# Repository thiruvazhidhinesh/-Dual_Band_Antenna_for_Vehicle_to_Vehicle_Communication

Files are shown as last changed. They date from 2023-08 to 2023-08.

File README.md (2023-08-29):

# Dual_Band_Antenna_for_Vehicle_to_Vehicle_Communication

<br>
In this project, a dual-band shared aperture antenna array is designed that operates 
at both the current Dedicated Short Range Communications (DSRC) band (viz. 5.9 GHz) 
and the future 5G millimeter-wave (mm-wave) band allocated for vehicle-to-vehicle 
(V2V) communications. The design consists of a 2 x 2 differentially fed patch array 
operating at 5.9 GHz, co-printed with a 1 x 2 series fed array operating on a single-layer 
substrate. Two antenna arrays have been designed using two different substrates: Rogers 
RT Duroid 5880 and FR4, and the effect of substrate material type on antenna 
performance has been studied. In particular, the shared aperture array designed using
Rogers operates from 5.854–6.001 GHz (DSRC band) with a bandwidth of 147 MHz and 
a gain of 10.63 dB intended for V2V communication. It also operates from 25.626-26.362 
GHz (5G mm-wave band) with a bandwidth of 736 MHz and a gain of 9.778 dB intended 
for 5G mm-wave communication. The ports of the array are highly isolated, with an 
isolation of greater than 50 dB between the DSRC band port and the 5G mm-wave band 
port

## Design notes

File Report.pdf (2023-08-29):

i

## LOW PROFILE DUAL BAND SHARED ANTENNA ARRAY FOR VECHICLE TO VECHICLE COMMUNICATION

Submitted by

THIRUVAZHI DHINESH KUMAR S (2019105594)

GOWTHAM N (2019105532)

DINESH M (2019105526)

KAVIYARASAN K (2019105021)

In partial fulfillment for the award of the degree of

BACHELOR OF ENGINEERING

in

ELECTRONICS AND COMMUNICATION ENGINEERING

COLLEGE OF ENGINEERING, GUINDY

ANNA UNIVERSITY::CHENNAI 600025

MAY 2023

i

APPENDIX 2

### ANNA UNIVERSITY: CHENNAI 600 025

BONAFIDE CERTIFICATE

Certified that this project report LOW PROFILE DUAL BAND SHARED ANTENNA

ARRAY FOR VECHICLE TO VECHICLE COMMUNICATION is the bonafide,

work of GOWTHAM N who carried the project work under my supervision.

SIGNATURE | SIGNATURE

Dr.M.Meenakshi

HEAD OF THE DEPARTMENT

PROFESSOR

DEPARTMENT OF ECE

COLLEGE OF ENGINEERING, GUINDY

ANNA UNIVERSITY

CHENNAI-600 025

Dr.M.Shanmugapriya

SUPERVISOR

ASSISTANT PROFESSOR

DEPARTMENT OF ECE

COLLEGE OF ENGINEERING, GUINDY

ANNA UNIVERSITY

CHENNAI-600 025

ii

ACKNOWLEDGEMENT

First and foremost, we thank God for an abundance of grace and has countless blessings

in making this work a great success.

We also express our sincere gratitude to our Head of the Department

Dr.M.MEENAKSHI, Professor, Department of Electronics and Communication

Engineering for her enthusiastic encouragement and support throughout the project.

We present our sincere thanks and gratitude to our project supervisor,

Dr.M.SHANMUGAPRIYA, Assistant Professor, Department of Electronics and

Communication Engineering for his wholehearted support, patience, valuable guidance,

technical expertise and encouragement in our project.

We thank all the teaching and non-teaching staff of Department of Electronics and

Communication Engineering, for their kind help and co-operation during the course of our

project.

iii

Chapter | Section | Title | Page
No. | No. | | No.
| | Abstract | i
| | List of Tables | iii
| | List of Figures | iv
1 | | Introduction | 1
| 1.1 | Motivation | 2
| 1.2 | Software Requirement | 3
| 1.3 | Software Overview | 3
2 | | Literature Survey | 4
3 | | Simulation Design Methodology and Results
3.1 | Design flow | 6
3.2 | CST Procedure | 9
3.3 | Analysis I | 10
3.4 | Analysis II | 15
3.5 | Analysis III | 21
3.6 | Analysis IV | 28
4 | Fabrication Process
4.1 | Laser cum chemical etching | 24
4.2 | Final Preparations | 27
4.3 | Laser depaneling | 28
4.4 | Network Analyzer | 29
4.5 | Calibration kit | 30
4.6 | SMA connector | 31
5 | Fabrication results
5.1 | Results | 33
6 | Conclusion | 36
| References | 37

APPENDIX 3

TABLE OF CONTENTS

i

ABSTRACT

In this project, a dual-band shared aperture antenna array is designed that operates

at both the current Dedicated Short Range Communications (DSRC) band (viz. 5.9 GHz)

and the future 5G millimeter-wave (mm-wave) band allocated for vehicle-to-vehicle

(V2V) communications. The design consists of a 2 x 2 differentially fed patch array

operating at 5.9 GHz, co-printed with a 1 x 2 series fed array operating on a single-layer

substrate. Two antenna arrays have been designed using two different substrates: Rogers

RT Duroid 5880 and FR4, and the effect of substrate material type on antenna

performance has been studied. In particular, the shared aperture array designed using

Rogers operates from 5.854–6.001 GHz (DSRC band) with a bandwidth of 147 MHz and

a gain of 10.63 dB intended for V2V communication. It also operates from 25.626-26.362

GHz (5G mm-wave band) with a bandwidth of 736 MHz and a gain of 9.778 dB intended

for 5G mm-wave communication. The ports of the array are highly isolated, with an

isolation of greater than 50 dB between the DSRC band port and the 5G mm-wave band

port.

ii

iii

LIST OF FIGURES

Figure No. | Title | Page No.
1 | Antenna design | 6
2 | Antenna array for DSRC band (CST Simulation) | 7
3 | Antenna array for 5G mm wave band (CST Simulation) | 8
4 | Design of combined arrays | 9
5 | Modified design with truncated corners and cross slots in 5.9 GHz array | 10
6 | Modified design with truncated corners and cross slots in 5.9 GHz array and cross slots in 5G mm wave band array | 10
7 | Modified design with cross slots in 5.9 GHz array and 5G mm wave band array | 11
8 | FR4 design | 11
9 | Modified FR4 design with truncated corners | 12
10 | S11 plot of design containing only 5.9 GHz array | 14
11 | S22 plot of design containing only 28 GHz array | 15
12 | VSWR plot of design containing only 5.9 GHz array | 15
13 | VSWR plot of design containing only 28 GHz array | 15
14 | S11 plot of 5.9 GHz array | 17
15 | S22 plot of 28 GHz array | 17
16 | VSWR plot for 5.9 GHz array | 18
17 | VSWR plot for 28 GHz array | 18
18 | Port 1 (5.9 GHz array) is excited | 19
19 | Port 2 (28 GHz array) is excited | 19
20 | Design without 180º Phase shift | 19

iv

Figure No. | Title | Page No.
21 | Design with 180º Phase shift | 19
22 | Varying patch length (Lp) of the DSRC band array | 22
23 | Varying patch width (Wp) of the DSRC band array | 22
24 | Varying patch length (LUp) of the 5G band array | 23
25 | Varying patch width (WUp) of the 5G band array | 23
26 | Varying thickness of the substrate EPOCH 1 | 24
27 | Varying thickness of the substrate EPOCH 2 | 24
28 | Varying thickness of the substrate EPOCH 3 | 24
29 | S11 Plot after slot introduction | 25
30 | S22 Plot after slot introduction | 25
31 | . Radiation pattern of shared array at 5.9 GHz – Rogers based design | 26
32 | Radiation pattern of shared array at 26 GHz – Rogers based design | 26
33 | VSWR at 5.9 GHz – Rogers based design | 27
34 | VSWR at 26 GHz – Rogers based design | 27
35 | Axial ratio at DSRC band– Rogers based design | 28
36 | Axial ratio at 5G mm-wave band– Rogers based design | 28
37 | S11 Plot for 5.9 GHz array – FR4 based design | 29
38 | S22 Plot for 5G mm-wave band – FR4 based design | 29
39 | Radiation pattern of shared array at 5.9 GHz – FR4 based design | 30
40 | Radiation pattern of shared array at 5G mm-wave band – FR4 based design | 30
41 | VSWR at 5.9 GHz – FR4 based design | 31

v

Figure No. | Title | Page No.
42 | VSWR at 5G Band – FR4 based design | 31
43 | Axial ratio at 5.9 GHz – FR4 based design | 31
44 | Axial ratio at 5G band – FR4 based design | 32
45 | RAYCUS LASER | 34
46 | IPG LASER | 34
47 | After reaction with FeCl3 | 35
48 | During tinning process | 36
49 | During Grinding process | 36
50 | LPKF Machine | 37
51 | Gerber of the array | 38
52 | Insertion of drills beats | 38
53 | Etched Substrate | 39
54 | Soldered ports | 39
55 | Vector Network Analyzer | 40
56 | Calkit 85220A | 40
57 | SMA Connector | 41
58 | Measured S11 of DSRC band | 42
59 | Measured VSWR at DSRC band | 43

vi

LIST OF TABLES

Table No. | Title | Page No.
1 | Dimensions for 5.9 GHz array | 7
2 | Dimensions for 5G mm-wave band antenna array | 8
3 | Dimensions for Antenna design using FR4 substrate | 12
4 | Dimensions for Antenna design using FR4 substrate with truncated corners | 13
5 | Radiation plots of individual antenna arrays | 16
6 | Radiation plots for combined array antenna design | 18
7 | Results without 180º Phase shift – 5.9 GHz array | 20
8 | Results with 180º Phase shift – 5.9 GHz array | 20
9 | Results without 180º Phase shift – 28 GHz array | 20
10 | Results with 180º Phase shift – 28 GHz array | 20
11 | Simulation results for 5.9 GHz array - Rogers based design | 26
12 | Simulation results for 26 GHz array - Rogers based design | 26
13 | Simulation results for 5.9 GHz array – FR4 based design | 30
14 | Simulation results for 5G mm-wave band – FR4 based design | 30

### CHAPTER 1

### INTRODUCTION

### 1.1 MOTIVATION:

Globally, road accidents claim 1.3 billion lives per year. Particularly in the US, road

accidents result in 38 thousand deaths per year. Improving the safety of the drivers is one of

the primary goals of the intelligent transportation system. The Federal Communications

Commission (FCC) allocated the 5.85-5.925GHz Dedicated Short Range Communications

(DSRC) band in the intelligent transport system (ITS) radio for vehicular communications.

This enabled the development of a virtual traffic light (VTL) algorithm to reduce traffic

congestion using vehicle-to-vehicle communication (V2V) and internet of things (IoT)

technologies. The role of the algorithm is to collect data such as speed, acceleration, and

direction of the vehicle from nearby vehicles as well as to control traffic without using

physical traffic lights. Field trials conducted in Pittsburgh showed that VTL can effectively

reduce 1) road accidents at the intersections by 70%, 2) carbon emissions, and 3) commute

time from 30.7 to 18.3 minutes. Currently, the US Department of Transportation and various

automobile industries use the 5.9 GHz safety band for automatic toll collection, traffic

congestion control, emergency vehicle warning, and intersection movement warning.

However, due to bandwidth restriction in the DSRC band, high data rate communications,

such as video streaming, are quite difficult to achieve. Therefore, the trend is to move

towards the millimeter-wave (mm-wave) spectrum for higher speed communications of >1

Gbps with wider bandwidth and reduced interference. In addition, the radios at mm-wave

are smaller in size and require low power consumption, implying inconspicuous integration

on the vehicular platforms. However, mm-wave spectrum suffers from large propagation

and atmospheric losses as well as attenuation due to rain and severe weather conditions.

These losses can be compensated by using high gain antenna arrays. Importantly, we need

a system capable of switching between the 5G mm-wave band, for high speed

communications, and well-established the DSRC band to meet the required communication

link quality of service during severe weather conditions.

Radios that can operate in the traditional low frequency bands and the new mm-wave

bands are called non-standalone devices. The main challenge is implementing these devices

in a single compact package when the two frequency bands are widely separate with a band

ratio >2:1. These dual-band systems offer high jamming, and interference protection, as well

as improvement in the channel capacity by making use of frequency diversity. Traditionally,

dual-band radios employ antennas designed using two separate single-band antennas or a

single structure that resonates at both bands. Various works have been reported of multi-

band antennas using a single feed. However, these single feed dual-band antennas require

additional RF components in the front-end for separate multiband operation. A more

efficient design for multiband operation is to use separate feed network for each operating

frequency bands by adopting a single or multilayer design. The main drawback of multilayer

designs are the multilayer fabrication technique that is expensive and increases the size of

the array. One of the simple, and easy fabrication technique is using a single layer Printed

Circuit Board (PCB). The implemented PCB shared aperture array operates at dual band

with highly isolated ports and provides gain improvement at upper band by utilizing the

higher order modes of the lower band array. In this work, a low profile non-standalone,

dual-band, shared aperture antenna array with gain improvement is designed for V2V

communication. The designed array consists of 4 patch antennas operating at 5.9 GHz

(DSRC) with a differential coax feed network and 2 patch antennas operating at 28 GHz

(5G mm-wave) with a series coax feed network, as shown. The array provides a dual-band

operation with high gain, high port-to-port isolation, and high efficiency.

### 1.2 SOFTWARE REQUIREMENT:

CST STUDIO SUITE

### 1.3 SOFTWARE OVERVIEW:

The designs and simulations in this project are based on the Computer Simulation

Technology (CST) microwave Studio suite which is a high performance electromagnetic

simulation software. There are two basic solver modules provided: time domain solver and

frequency domain solver. The two solvers are totally different. Time domain solver is used

for non-resonant structures and frequency domain solver contains alternatives for highly resonant structures. Beside frequency domain solver has the option of utilizing tetrahedral

mesh that can discrete the structure better which is not available with in time domain solver.

In addition, time domain solver is only for normal incidence but frequency domain solver

can be used for off–normal incidences. CST contains several different simulation methods,

including the finite integration technique(FIT), finite element method (FEM), transmission

line matrix (TLM), multilevel fast multiples method (MLFMM) and particle in cell (PIC),as

well as Multiphysics solvers for other domains of physics with links to electromagnetics.

### CHAPTER 2

### LITERATURE SURVEY

### 2.1.1 Low Profile Dual-Band Shared Aperture Array for Vehicle-to-

Vehicle Communication

In this paper, it was observed that a non-standalone dual-band shared aperture

antenna array can be operated at both the current Dedicated Short-Range Communications

(DSRC) band (viz. 5.9 GHz) and the future 5G millimeter-wave (mm-wave) band (viz. 28

GHz) allocated for vehicle-to-vehicle (V2V) communications.

### 2.1.2 Left-Handed Circularly Polarized Two-Element Antenna Array for

Vehicular Communication

From this paper, it was observed that truncated opposite corners and introduction

of cross slots move the polarization of an antenna from linear towards circular and cause

narrow beam width.

2.1.3 Vehicle Platform Effects on Performance of Flexible, Lightweight,

and Dual-Band Antenna for Vehicular Communications

From this paper, the impact of the ground, of the vehicle surroundings and of the

car body on signal transmission and reception of a dual-band microwave antenna tested

on two automotive plastic parts on a convertible vehicle for cellular and Cellular - Vehicle

to Everything (C-V2X) communications was observed.

### 2.1.4 Combined LTE and IEEE 802.11p Antenna for Vehicular

Applications From this paper, the evolution of IEEE 802.11 to IEEE 802.11p with

added V2V and V2X technologies which focuses on traffic safety and traffic efficiency

has been observed. The observed results show that the antennas are well matched and well

isolated for both LTE and V2X.

### 2.1.5 A Hybrid-Equivalent Surface-Edge Current Model for Simulation

of V2X Communication Antennas with Arbitrarily Shaped Contour

From this paper, it was observed that equivalent models of antennas are useful for

the fast simulation of vehicle-to-everything (V2X) communication. However, the full-

wave methods are accurate but computationally intensive, and they need a

supercomputing platform to simulate V2X communication.

### 2.1.6 A Pillbox Based Dual Circularly-Polarized Millimeter-Wave Multi-

Beam Antenna for Future Vehicular Radar Applications

From this paper, it was observed that a series-fed microstrip line based dual CP

leaky-wave antenna (LWA) array, which has a symmetrical structure can be used to obtain

both left-hand circular polarization (LHCP) and right-hand circular polarization (RHCP)

by switching the exciting current direction of the microstrip line.

### 2.1.7 A dual band omni-directional antenna for WAVE and Wi-Fi

From this paper, it was observed that a dual band antenna is capable of operating in

both the WAVE and Wi-Fi bands. This antenna is observed to be simple, easy-to-produce

and inexpensive; it can be a cost-effective alternative to use of multiple directional

antennas for vehicles.

2.1.8 A Miniaturized Wideband Antenna for Vehicular Communication,

WiMAX, and WLAN Applications

From this paper, it was observed that Rogers RT/Duroid 5880 TM with dielectric

constant 2.2 and loss tangent tan δ = 0.0009 has lower loss, higher efficiency and wider

bandwidths can be achieved. And also, with an increase in permittivity, the capacitance

increases. With an increase in capacitance, the resonant frequency decreases.

### CHAPTER 3

### SIMULATION DESIGN METHODOLOGY AND RESULTS

### 3.1 DESIGN FLOW:

### 3.1.1 Design flow using Rogers substrate:

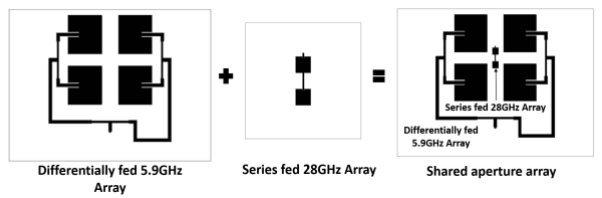
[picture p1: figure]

Figure 1. Antenna design

The proposed antenna structure as per the base reference paper consists of two main parts,

as shown in Figure. 1, the first part 5.9GHz differential fed array and the second part is

series fed 5G mm wave array. Each of the array and coaxially fed and printed upon Rogers

substrate. A 28GHz array has been inserted in a space between the 5.9GHz array for future

5G mm wave communication.

Figure 2. Antenna array for DSRC band (CST Simulation)

Table 1: Dimensions for 5.9 GHz array

Initially, the antenna array design for 5.9 GHz has been completed as in Figure 2 with

differential feeding and simulated to observe the results without presence of a second port

in order to compare the results obtained with presence of another port for 5G mm wave

band which provides information about the isolation between the ports. Then, another new

antenna array for 5G mm wave band has been completed as in Figure 3 with serial feeding

and similarly simulation has been done to observe the results without presence of first port

which was used for 5.9 GHz.

PARAMETERS | VALUES(mm)
W x L x h | 75 x 100 x 0.52
Wp x Lp x hp | 19 x 16.7 x 0.035
x | 8
y | 6
Wf x Lfi x hf | 1.6 x 5.85 x 0.035
W50Ω | 1.6
W70.7Ω | 0.9
Wgap | 0.16

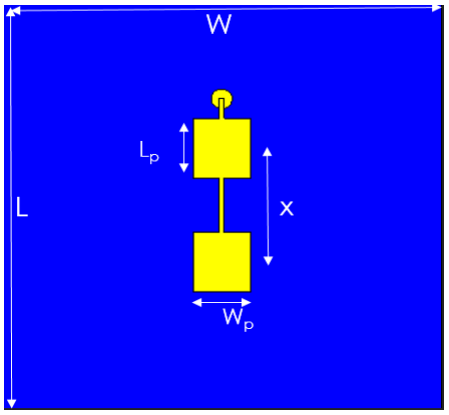
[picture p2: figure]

Figure 3. Antenna array for 5G mm wave band (CST Simulation)

Table 2: Dimensions for 5G mm wave band antenna array

After obtaining the results of separate antenna arrays from simulation, both these arrays

are mounted on a Rogers substrate material to obtain the results with presence of both

ports – Port 1 and Port 2 which are used for exciting 5.9 GHz and 5G mm wave frequency

band. In the combined design, 5.9 GHz array is fed using differential feeding and 5G mm

wave band array is fed using serial feeding so that the latter can be placed in the space

available within the former and the dimensions of both these arrays are same as of the

individual array antennas. The antenna array design for combined applications of DSRC

band and 5G mm wave band has been completed as in Figure 4 and the results obtained

is discussed in section 3.3 .

PARAMETERS | VALUES(mm)
W x L x h | 25 x 25 x 0.52
Wp x Lp x hp | 3.25 x 3.67 x 0.035
x | 8
Wf x Lfi x hf | 0.3 x 1.24 x 0.035

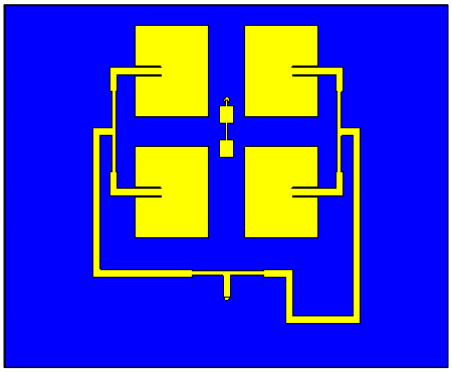
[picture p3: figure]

Figure 4. Design of combined arrays

Using the design shown in Figure 4, the resonant frequencies obtained were 5.97

GHz and 28 GHz. For V2V communication the resonant frequency should be 5.9 GHz.

In India for 5G, 26 GHz is in use. So to shift the frequencies to left, slots were introduced

and the corners of each patch are truncated as shown in Figure 5. Introduction of cross

slots, brings forth the advantage of replacing a single radiating element with three

radiating elements in place. Increasing the radiating elements with small distance of

separation between the elements will narrow down the radiation and increase directivity

along with gain. Introducing truncated corners in the regions of the patch where surface

current is minimum enhances the performance of the antenna and moves the polarization

type of the antenna from linear to circular polarization. Considering these advantages,

modifications in the design has been performed through series of parameter sweeps and

analysis of surface current distribution. With the design shown in Figure 4, three different

modified arrays have been designed as shown in the following figures.

Figure 5. Modified design with truncated corners and cross slots in 5.9 GHz array

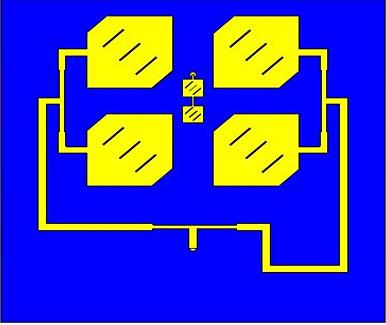
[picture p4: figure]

Figure 6. Modified design with truncated corners and cross slots in 5.9 GHz array and

cross slots in 5G mm wave band array

Figure 7. Modified design with cross slots in 5.9 GHz array and 5G mm wave band

array

### 3.1.1 Design flow using FR4 substrate:

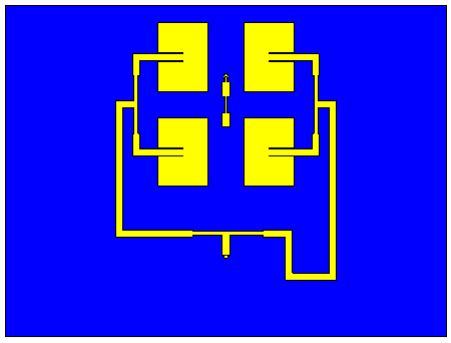
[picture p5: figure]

Figure 8. FR4 design

Previous designs were made on substrate based on Rogers. Rogers can be

used in any environment. But in V2V communication FR4 can also be used, since the

environment does not cause a major impact on the performance of the antenna. Using

FR4, the antenna can be made with low cost without degradation in performance.

Theoretical calculations have been performed with respect to FR4 substrate and the

length and width of the patch of DSRC band array and 5G mm wave band array have

been determined and the design has been modified accordingly. The modified

dimensions are displayed in Table 3.

Table 3: Dimensions for Antenna design using FR4 substrate

Introduction of slots in arrays mounted FR4 substrate leaded to very low resonant

frequencies compared to the desired ones. So owing to the advantages in introduction of

truncated corners, the FR4 design has been modified with introduction of truncated

corners in the patch and the corresponding design is depicted in Figure 9 and the

dimension values are displayed in Table 4.

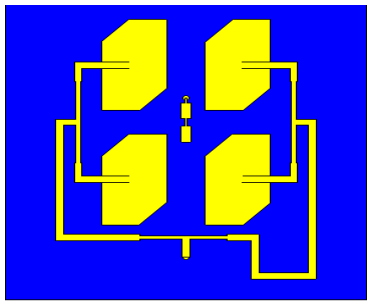
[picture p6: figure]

Figure 9. Modified FR4 design with truncated corners

PARAMETERS | VALUES(mm)
W x L x h | 75 x 100 x 0.52
Wp x Lp x hp | 11.53 x 15.47 x 0.035
x | 8
y | 6
Wf x Lfi x hf | 1.6 x 5.85 x 0.035
W50Ω | 1.6
W70.7Ω | 0.9
Wgap | 0.16
Wu x Lu x hu | 1.66 x 3.26 x 0.035
Xu | 7
Wf x Lfi x hf | 0.3 x 1.24 x 0.035

The results obtained using this antenna are discussed in section NN. The design

shown in Figure 9 is used for fabrication process and the fabricated antenna is analyzed

in section NN.

Table 4: Dimensions for Antenna design using FR4 substrate with truncated corners

### 3.2 CST PROCEDURE:

Create Ground surface by using a new brick and set the copper as material. Set the

dimensions length, width in y length and x length and set 0.035 as height in z length.

Design a substrate with the same length and width as that of the ground component.

Set the height starting from zmax of ground plane and set zmax of the substrate to have the

derived height value. Set the material for the substrate to be Rogers.

Now to design the patch on top of the substrate, use new block with copper material

PARAMETERS | VALUES(mm)
W x L x h | 75 x 75 x 1.67
Wp x Lp x hp | 23 x 13.5 x 0.035
x | 8
y | 6
Wf x Lfi x hf | 1.6 x 5.85 x 0.035
W50Ω | 1.6
W70.7Ω | 0.9
Wgap | 0.16
Wu x Lu x hu | 2 x 4 x 0.035
Xu | 7
Wf x Lfi x hf | 0.3 x 1.2 x 0.035

and use the lengths and widths specified in table TT. Design of each patch in antenna array

is made using a new block. The feed lines for each element are designed using the

parametric values derived and depicted in table TT. To introduce slots on the patches make

new blocks with the dimensions of the slots and use boolean operation to cut the patch.

Same is to be followed for introducing truncated corners. The translate option is used to

rotate the slots and the truncated corner by specifying appropriate angles.

This sequence of steps are carefully followed to get the desired design of the

antenna. The parameters for each brick should be given a variable so that the parameter

sweeps can be performed easily. A SMA (Sub Miniature version A) connector is used to

provide supply. The SMA connector is semi precision coaxial RF connectors developed

as a minimal connector interface for coaxial cable with a screw-type coupling mechanism.

The results will be varied when SMA connector is used due to noise and the load

impedances. The cylinder block is to be made use of, to design the SMA connector. The

inner cylinder should have a radius of 0.6 mm and material of Copper. The middle cylinder

should have a inner radius of 0.6 mm and outer radius of 1.4 mm and material should be

Teflon. The outer cylinder should have a inner radius of 1.4 mm and outer radius of 2.2

mm and the material should be Copper. The outer cylinder should touch the ground plane.

The inner cylinder should touch the port of the array of patches to excite the array. Using

the steps mentioned two SMA connectors are to be designed for two port – one for 5.9

GHz array and the other for 5G array.

### 3.3 ANALYSIS I:

The antenna design containing only 5.9 GHz array shown in Figure 2 is excited

first. Then the antenna design containing only 28 GHz array shown in Figure 3 is excited.

Figure 10. S11 plot of design containing only 5.9 GHz array

The S11 and VSWR plots for both the cases are depicted below.

The S11 plot shows how return loss occur at the resonant frequencies. The desired

level of return loss at resonant frequencies is that it should be less than or equal to -10dB.

For 5.9 GHz array, S11 obtained at 5.98 GHz is about -18dB. For 28 GHz array, the S11

obtained at 28.13 GHz is about -30dB.

The VSWR which tells about the reflecting wave coefficient should be in the range

between 1 and 3 for industrial use. For 5.9 GHz array the VSWR obtained the is near 1.3

and for 28 GHz array VSWR obtained is near 1.09. The individual patch elements are

designed to radiate at the desired resonant frequencies. The effect of array can be seen in

the radiation pattern, in efficiency, directivity and gain. The radiation pattern obtained by

exciting the antenna designs shown in Figure 2 and Figure 3 are depicted in Table 5.

Figure 12. VSWR plot of design containing only 5.9 GHz array

Figure 13. VSWR plot of design containing only 28 GHz array

Figure 11. S22 plot of design containing only 28 GHz array

Table 5: Radiation plots of individual antenna arrays

Radiation pattern of 5.9 GHz array

Parameter | Value
Single element | 2 x 2 array
Gain | 5.54 dB | 9.99 dB
Directivity | 6.478 dB | 10.9 dB
Efficiency | 80.647 % | 79 %
HPBW | 91º | 55.1º
VSWR | 1.1 | 1.465

Radiation pattern of 28 GHz array

Parameter | Value
Single element | 1 x 2 array
Gain | 6.11 dB | 10.2 dB
Directivity | 7.77 dB | 10.4 dB
Efficiency | 68.25 % | 94.7 %
HPBW | 72.4º | 36.8º
VSWR | 1.55 | 1.074

For 5.9 GHz and 28 GHz, when switching from an individual element to an array,

gain and directivity have increased and VSWR has decreased. The analysis made by

mounting both the array on a single Rogers substrate is discussed below.

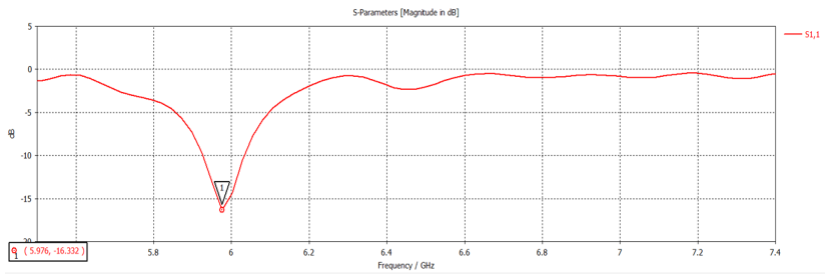
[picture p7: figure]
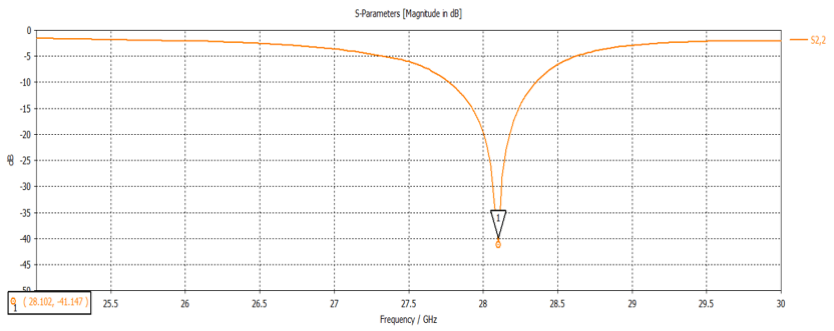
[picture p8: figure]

The S11 and S22 plots are obtained by exciting the ports of each array on the

antenna design shown in figure 4. S11 obtained at 5.976 GHz is about -17dB and S22

obtained at 28.1 GHz is about -41dB. Both S11 and S22 values are good, indicating most

of the power fed is radiated.

The VSWR plots are depicted in Figure 16 and 17. VSWR obtained for 5.9GHz is

about 1.3 and for 28GHz is 1. This indicates that the reflected wave is very minimum

preferable for industrial use.

Figure 14. S11 plot of 5.9 GHz array

Figure 15. S22 plot of 28 GHz array

Figure 16. VSWR plot for 5.9 GHz array

Table 6. Radiation plots of combined array antenna design

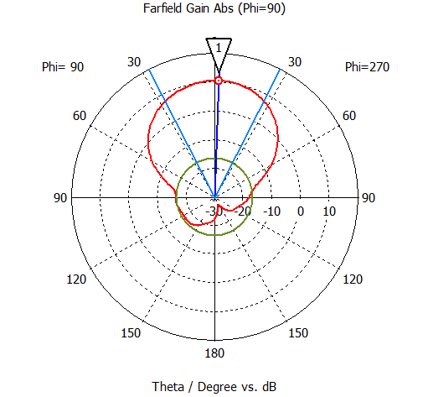
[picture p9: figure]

Radiation pattern for 5.9 GHz array

Parameter | Value
Gain | 10.5 dB
Directivity | 11.1 dB
Efficiency | 86.6%
HPBW | 54.5º
VSWR | 1.36

Radiation pattern for 28 GHz array

Parameter | Value
Gain | 11.3 dB
Directivity | 11.6 dB
Efficiency | 93.41%
HPBW | 26.8º
VSWR | 1.02

Figure 17. VSWR plot for 28 GHz array

Table 6 shows the radiation patterns obtained by exciting the ports individually in

the combined array design shown in Figure 4. When both the arrays are mounted on the

single substrate, minor lobes are introduced in the radiation. To reduce the minor lobes

and Half Power Beam Width to increase the directivity, slots are introduced. The analysis

done for the antenna design after slots and the truncated corner are introduced, is discussed

in section 3.5.

Isolation between the ports is observed in Figure18 and Figure19. The ports are

excited individually and observed that power fed to one port is not transferred to the other

port.

### 3.4 ANALYSIS II: SIGNIFICANCE OF 180º PHASE SHIFT:

DESIGN VARIATIONS:

In this antenna, to match the impedance between feed and patch elements, a Quarter

wavelength transformer is used. In this transformer, a line having length of one fourth of

operating wavelength and characteristic impedance of square root times of characteristic

impedance of feed line, is used to connect feed with patch elements.

Figure 18. Port 1 (5.9 GHz array) is excited

Figure 19. Port 2 (28 GHz array) is excited

Figure 20. Design without 180º Phase shift

Figure 21. Design with 180º Phase shift

By controlling the phase difference between powers fed to each element of an

antenna array, the radiation pattern can be controlled.

180º out of phase signals when fed to the elements, the lobes can be combined to

form a single major lobe.

In 5.9 GHz array, the signal fed to the left 2 elements is 180 degree out of phase

with the signal fed to the right 2 elements. This is facilitated by the extended line having

length of half of the operating wavelength connected to the right portion of the array. The

effect can be observed in the radiation patterns

### 5.9 GHz RESULTS VARIATION:

Table 7. Results without 180º Phase shift – 5.9 GHz array

### 28 GHz RESULTS VARIATION:

Table 9. Results without 180º Phase shift – 28 GHz array

### 3.5 ANALYSIS III:

MODIFIED ROGERS DESIGN SIMULATION RESULTS

The Rogers design described in the previous section (Schematic can be seen in the

figure) is modified by the introduction of cross slots in both DSRC band array and 5G band

array referring to the IEEE paper Left-Handed Circularly Polarized Two-Element

Antenna Array for Vehicular Communication briefly known as LHCP. This modified

Parameter | Value
Gain | 10.5 dB
Directivity | 11.1 dB
Efficiency | 86.6%
Parameter | Value
Gain | 8.96 dB
Directivity | 9.34 dB
Efficiency | 89.7%
Parameter | Value
Gain | 11.3 dB
Directivity | 11.6 dB
Efficiency | 93.4%
Parameter | Value
Gain | 8.15 dB
Directivity | 9.24 dB
Efficiency | 77.8%

Table 8. Results with 180º Phase shift – 5.9 GHz array

Table 10. Results with 180º Phase shift – 28 GHz array

Rogers design is shown in the figure. After this modification, the corresponding simulation

results have been studied.

Compared to the conventional rectangular patch antenna, slot loading antennas give the

better performance in

- Resonant frequency,
- High return loss,
- Wider bandwidths etc.

Though the introduction of cross slots brings better efficiency and directivity etc. in

the antenna, it is necessary to bring the resonant frequencies to the required place (i.e.,

DSRC band and 5G band). Thus, it becomes indispensable to do parameter sweeps to bring

the resonant frequencies to the desired place.

Shift in the resonance frequency to left or right side while designing the micro-strip

patch antenna can be done in many ways.

Two methods in their most basic form are:

a) By changing the length (dimension) of the patch.
b) By changing the dielectric constant of the substrate.

Moreover, there are also some other techniques to reduce the resonance frequency

of the patch antenna, such as DGS, Metamaterial etc. Apart from this, ABS cover over the

patch (used generally to protect against weather) creates effect to move frequency towards

left (decrease in resonance frequency).

As the first case, it was attempted to change the dimension (length and width) of the

array patch in both DSRC band and 5G band.

The following changes have been done and the parameter sweeps have been conducted:

- Varying patch length of the DSRC band array
- Varying patch width of the DSRC band array

- Varying patch length of the 5G band array
- Varying patch width of the 5G band array
- Varying thickness of the substrate

Figure 22. Varying patch length (Lp) of the DSRC band array

From the above figure, it can be inferred that when the length of the patch is increased, the

resonant frequency shifts towards left (decrease in the resonant frequency) and vice versa.

Figure 23. Varying patch width (Wp) of the DSRC band array

From the above figure, it can be inferred that when the width of the patch is

increased, the resonant frequency is shifted towards left (i.e., there is a decrease in the

resonant frequency) and vice versa.

Figure 24. Varying patch length (LUp) of the 5G band array

The same variations can be observed from the above figure for the 5G band array as

like the DSRC band array.

Figure 25. Varying patch width (WUp) of the 5G band array

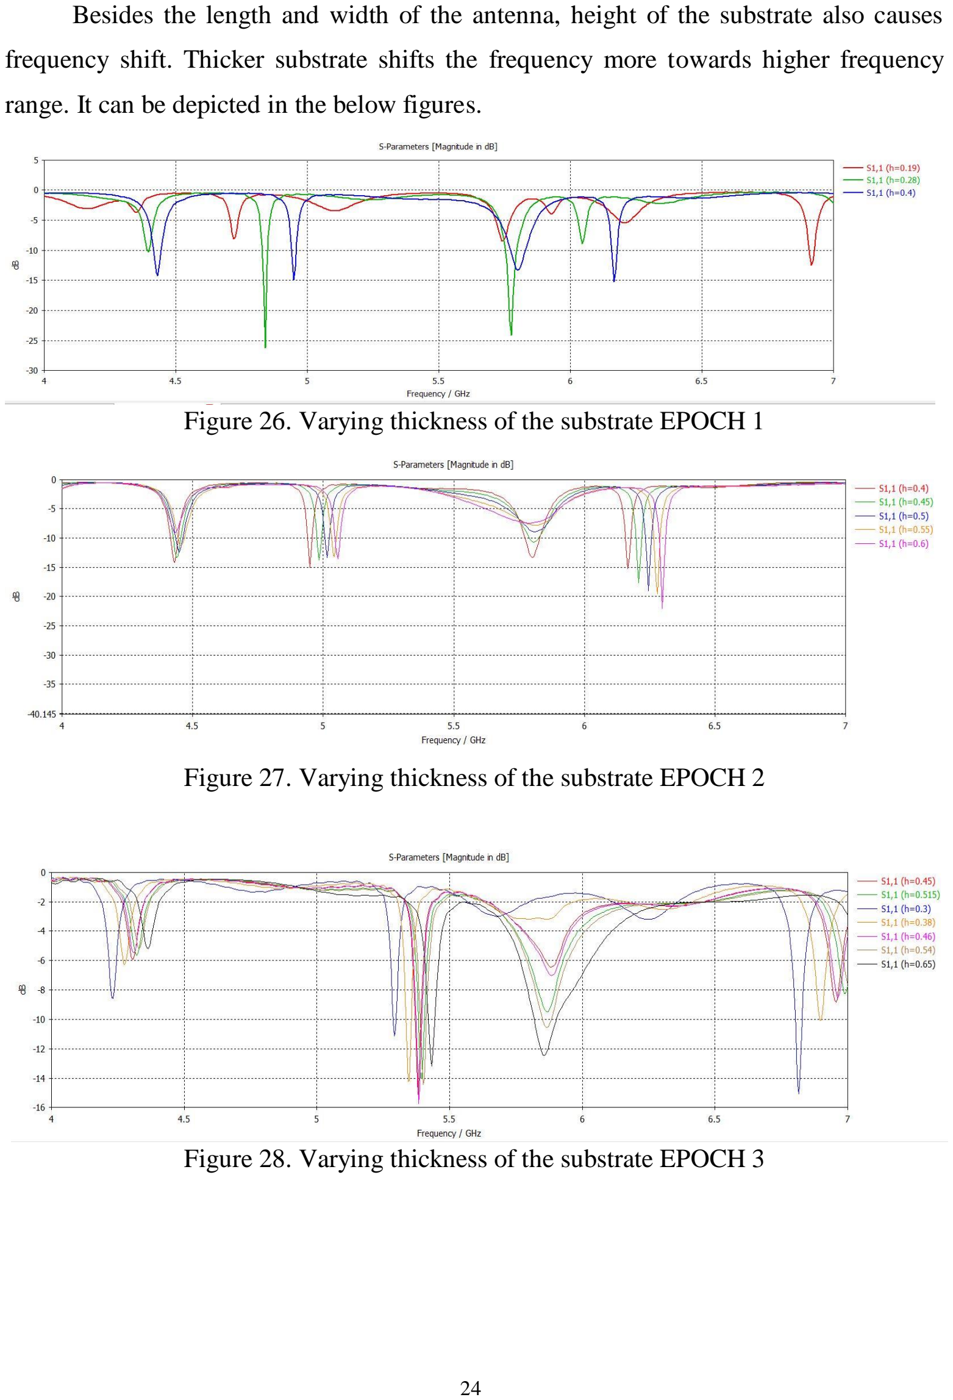
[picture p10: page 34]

Besides the length and width of the antenna, height of the substrate also causes

frequency shift. Thicker substrate shifts the frequency more towards higher frequency

range. It can be depicted in the below figures.

Figure 26. Varying thickness of the substrate EPOCH 1

Figure 27. Varying thickness of the substrate EPOCH 2

Figure 28. Varying thickness of the substrate EPOCH 3

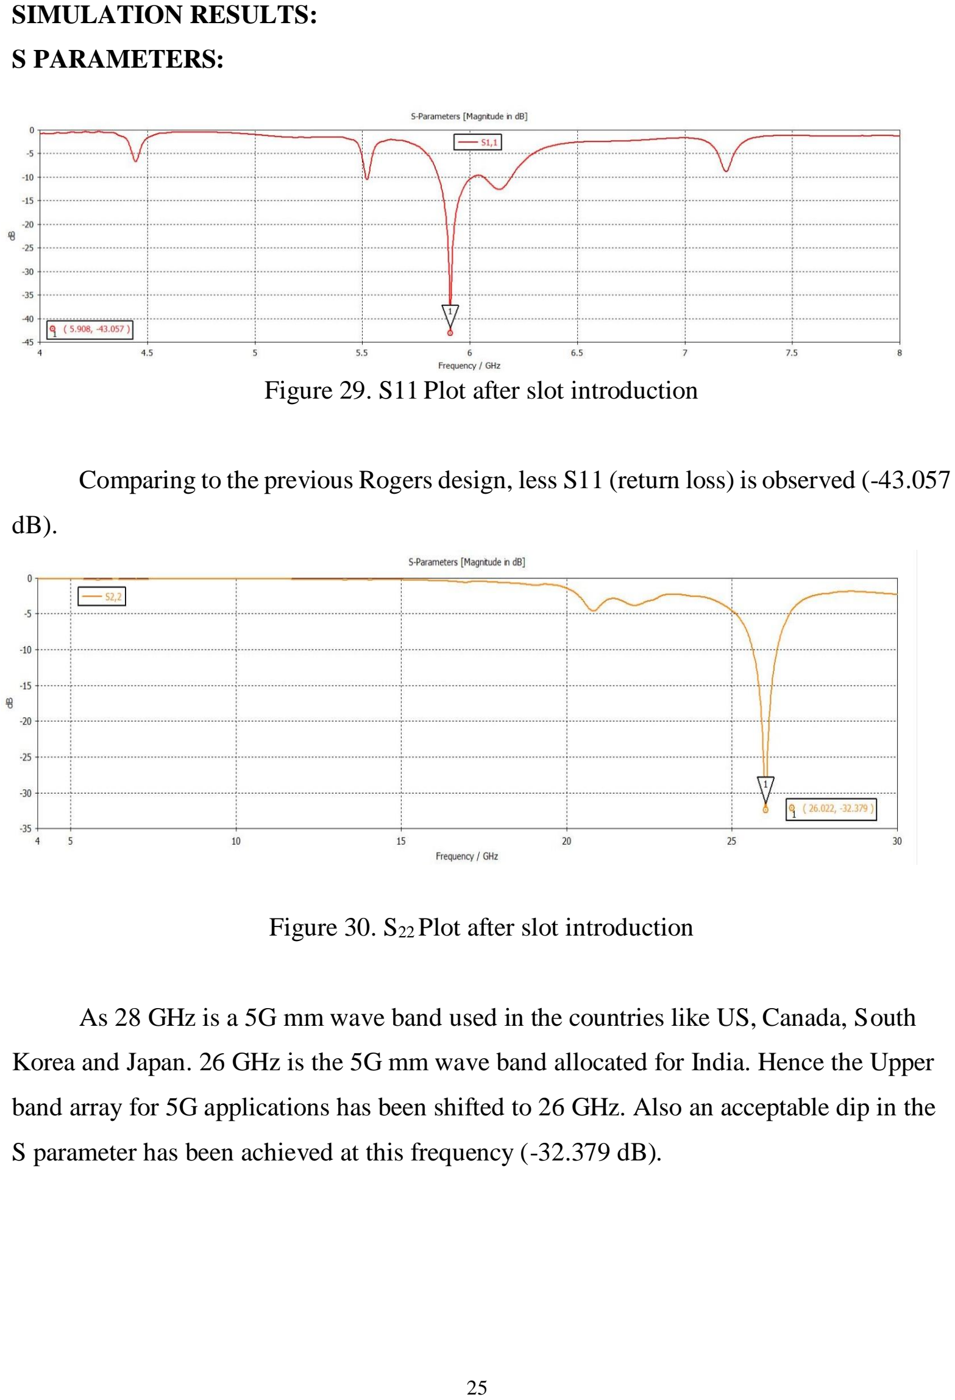
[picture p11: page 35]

SIMULATION RESULTS:

S PARAMETERS:

Figure 29. S11 Plot after slot introduction

Comparing to the previous Rogers design, less S11 (return loss) is observed (-43.057

dB).

Figure 30. S22 Plot after slot introduction

As 28 GHz is a 5G mm wave band used in the countries like US, Canada, South

Korea and Japan. 26 GHz is the 5G mm wave band allocated for India. Hence the Upper

band array for 5G applications has been shifted to 26 GHz. Also an acceptable dip in the

S parameter has been achieved at this frequency (-32.379 dB).

RADIATION PATTERN:

Figure 31. Radiation pattern of shared

array at 5.9 GHz – Rogers based design

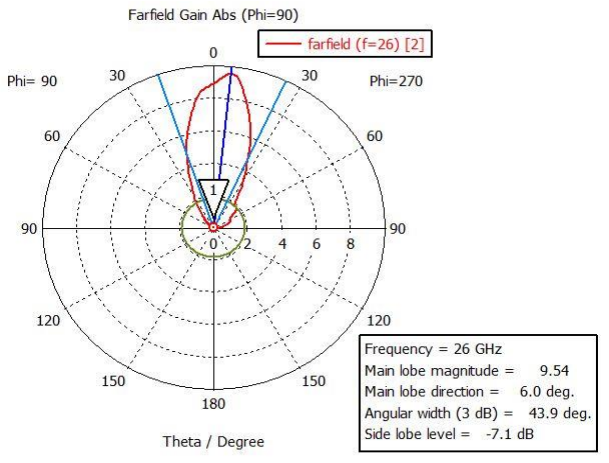
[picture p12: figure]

Figure 32.Radiation pattern of shared

array at 26 GHz – Rogers based

design

The figure shows that due to the introduction of cross slots in the previous Rogers

design, the minor lobe found in the radiation pattern of that design got eliminated and as a

result, the efficiency of the modified Rogers design has been increased.

Parameter | Value
Gain | 10.5 dB
Directivity | 11.1 dB
Efficiency | 86.6%
HPBW | 54.5º
VSWR | 1.36
Parameter | Value
Gain | 9.778 dB
Directivity | 9.974 dB
Efficiency | 95.6%
HPBW | 43.9º
VSWR | 1.03

Table 11.

Simulation results for 5.9 GHz array

-Rogers based design

Table 12.

Simulation results for 26 GHz array

-Rogers based design

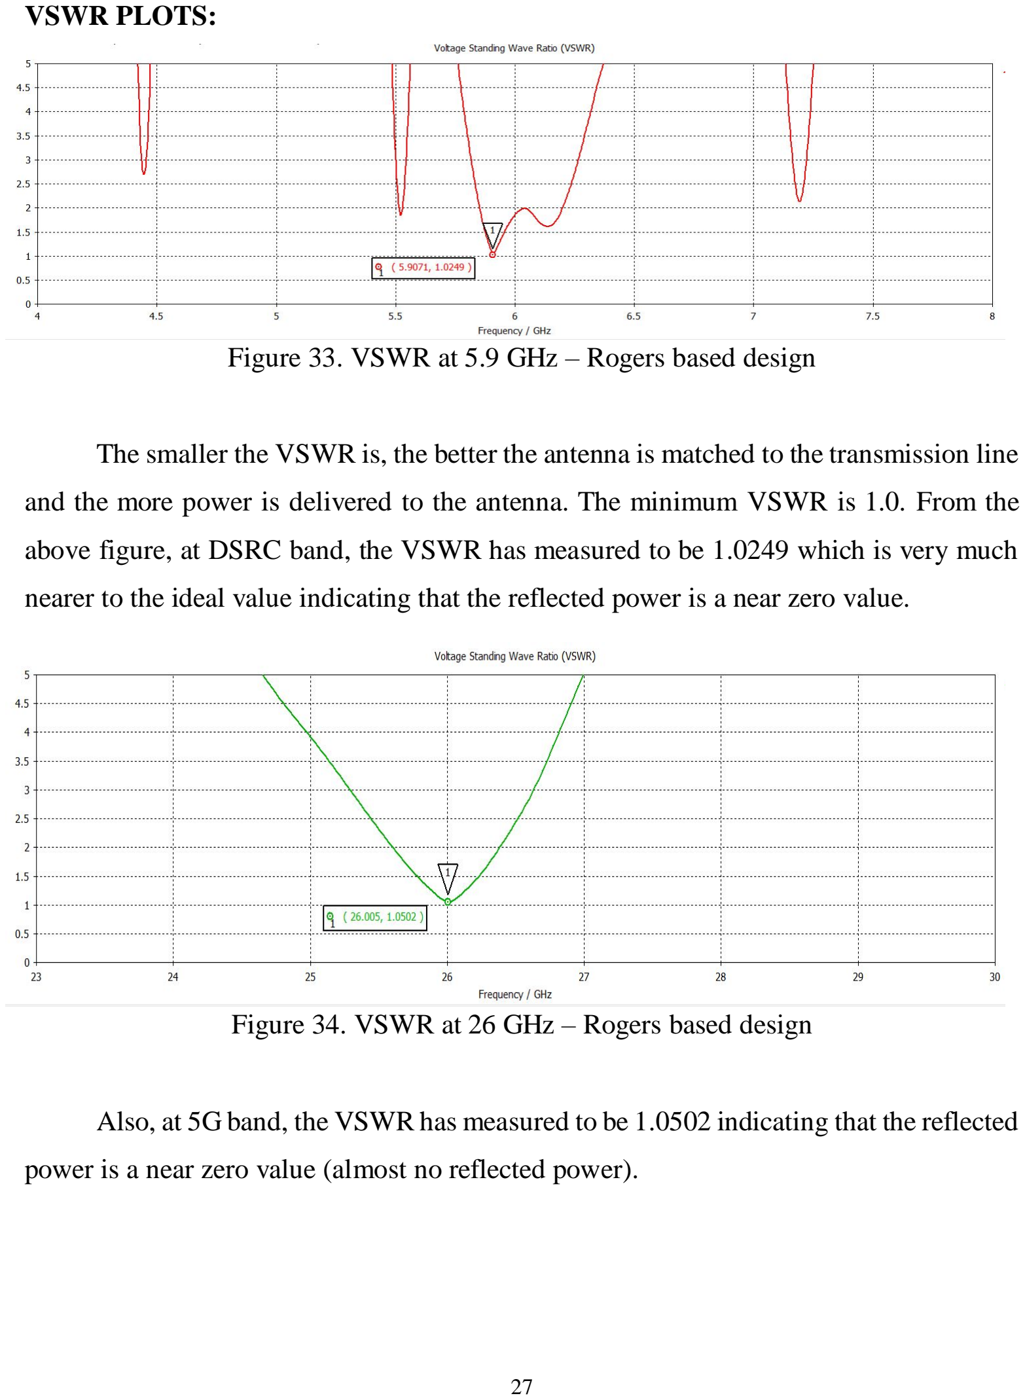
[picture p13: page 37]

VSWR PLOTS:

Figure 33. VSWR at 5.9 GHz – Rogers based design

The smaller the VSWR is, the better the antenna is matched to the transmission line

and the more power is delivered to the antenna. The minimum VSWR is 1.0. From the

above figure, at DSRC band, the VSWR has measured to be 1.0249 which is very much

nearer to the ideal value indicating that the reflected power is a near zero value.

Figure 34. VSWR at 26 GHz – Rogers based design

Also, at 5G band, the VSWR has measured to be 1.0502 indicating that the reflected

power is a near zero value (almost no reflected power).

AXIAL RATIO:

Axial ratios are often quoted for antennas in which the desired polarization is

circular. The ideal value of the axial ratio for circularly polarized fields is 0 dB. The axial

ratio for an ellipse is larger than 1 (> 0 dB) and less than 3 dB. The axial ratio for pure

linear polarization is infinite, because the orthogonal components of the field is zero.

Referring to the above diagrams, at both DSRC and 5G band axial ratio appears to be in

the range of 5.0 dB at DSRC band and 4.4 dB at 5G band. Hence, the modified Rogers

design has the properties of Elliptical polarization.

### 3.6 ANALYSIS IV:

FR4 DESIGN SIMULATION RESULTS:

- Owing to the evolution of vehicular communication, it is important to reduce the

overall design cost of the system by choosing cost-efficient materials for the design.

- Since the cost of Rogers substrate is very high, FR4 substrate has been chosen for

design consideration which is a low-cost material.

- Hence, the design has been modified with material from Rogers to FR4 and

expected results have been achieved.

Figure 35. Axial ratio at DSRC

band– Rogers based design

Figure 36. Axial ratio at 5G mm-

wave band– Rogers based design

S-PARAMETERS:

Figure 37. S11 Plot for 5.9 GHz array – FR4 based design

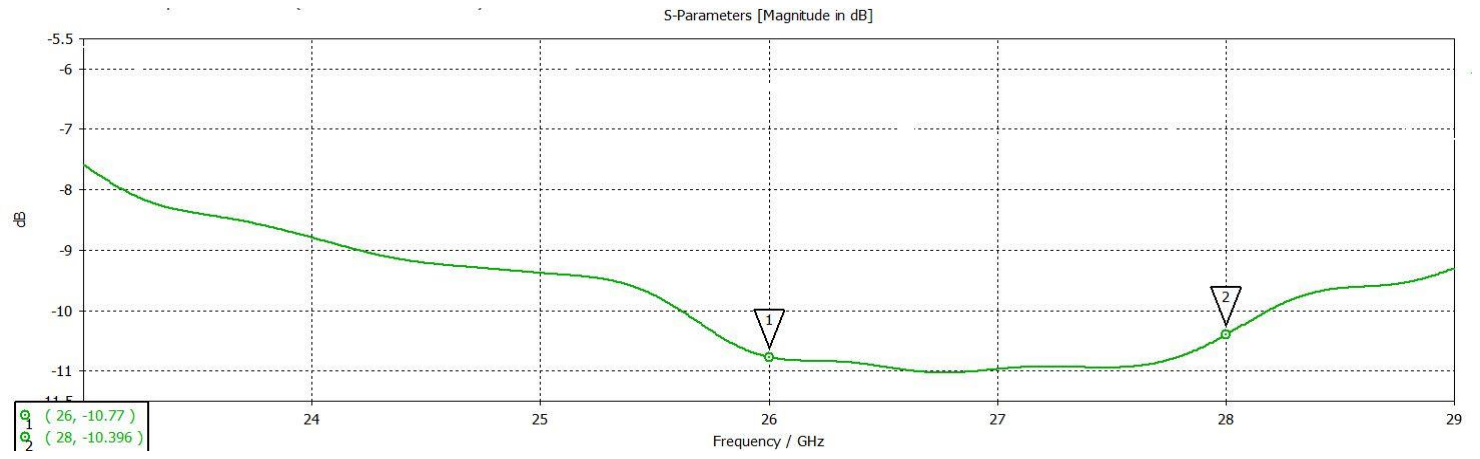
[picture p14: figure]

Figure 38. S22 Plot for 5G mm-wave band – FR4 based design

From the above figure, during the excitation of both DSRC band array and 5G band

array, it has been observed that the S11 has a considerable dip of about -31.424 dB and

S22 with a dip of -10.77 dB at 26 GHz and -10.396 dB at 28 GHz. Hence at 5G band, a

much wider bandwidth (greater than 2 GHz) is achieved.

RADIATION PATTERN:

Different antenna designs produce different radiation patterns. The complexity of

the pattern depends on the antenna's design and construction. Antenna specification sheets

sometimes come with three-dimensional projections. More often, a two-dimensional plot

can be observed and visual representation of Radiation pattern in three-dimensional

pattern gives us more information.

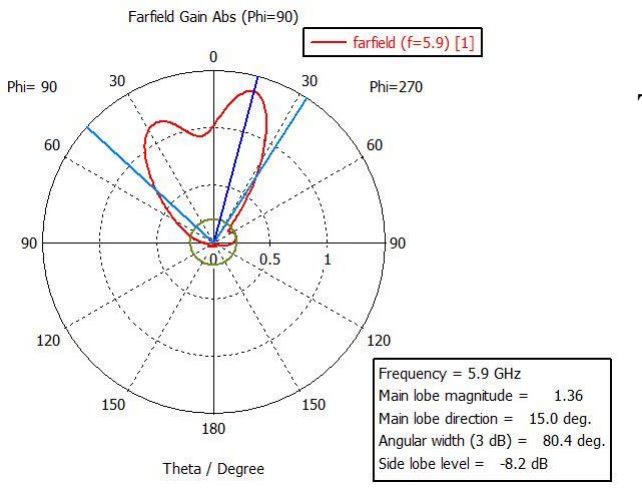
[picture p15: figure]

Figure 39. Radiation pattern of shared

array at 5.9 GHz – FR4 based design

Figure 40. Radiation pattern of shared

array at 5G mm-wave band – FR4 based

design

The obtained results are as expected and supports V2V communication and 5G mm-

wave band. But still parameters like efficiency and radiation pattern are better in the

antenna array made up of Rogers substrate. FR4 is popularly known for its cost efficiency

and is used worldwide.

Parameter | Value
Gain | 6.87 dB
Directivity | 8.138 dB
Efficiency | 64.82%
HPBW | 80.4º
VSWR | 1.0801
Parameter | Value
Gain | 7.201 dB
Directivity | 9.188 dB
Efficiency | 63.21%
HPBW | 19.4º
VSWR | 1.8658

Table 13. Simulation results for 5.9 GHz array –

FR4 based design

Table 14. Simulation results for 5G mm-wave band –

FR4 based design

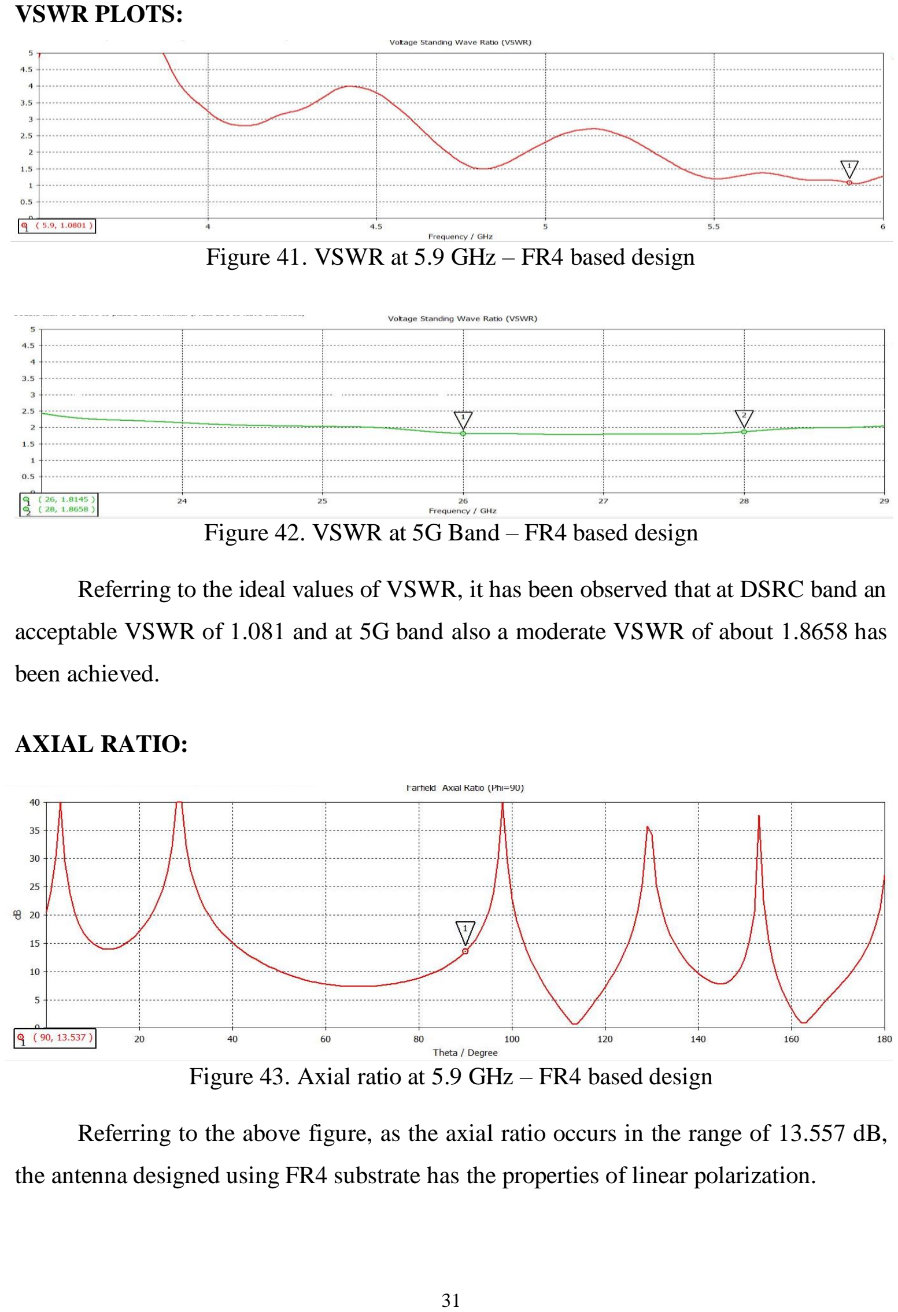
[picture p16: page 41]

VSWR PLOTS:

Figure 41. VSWR at 5.9 GHz – FR4 based design

Figure 42. VSWR at 5G Band – FR4 based design

Referring to the ideal values of VSWR, it has been observed that at DSRC band an

acceptable VSWR of 1.081 and at 5G band also a moderate VSWR of about 1.8658 has

been achieved.

AXIAL RATIO:

Figure 43. Axial ratio at 5.9 GHz – FR4 based design

Referring to the above figure, as the axial ratio occurs in the range of 13.557 dB,

the antenna designed using FR4 substrate has the properties of linear polarization.

Figure 44. Axial ratio at 5G mm-wave band – FR4 based design

From the above figure, it has been observed that the axial ratio at 5G mm-wave

band is 16.209 dB, stating that port 2 of the FR4 designed antenna operating at 5G mm-

wave band has the properties of linear polarization.

### CHAPTER 4

### FABRICATION PROCESS

### 4.1 LASER CUM CHEMICAL ETCHING

This chapter discusses the various techniques used for antenna fabrication. The antennas

fabricated using different techniques were then compared for their performance, to

identify the most suitable fabrication methodology.

→ | → | →
↓
← | ← | ← | ←

### 4.1.1 LASER ENGRAVING:

Laser engraving is a process that vaporizes materials into fumes to engrave permanent,

deep marks. The laser beam acts as a chisel, incising marks by removing layers from the

surface of the material. The laser hits localized areas with massive levels of energy to

generate the high heat required for vaporization. Laser engraving sublimates the material

surface to create deep crevices. This means that the surface instantly absorbs enough

energy to change from solid to gas without ever becoming a liquid. To achieve

sublimation, the laser engraving system must generate enough energy to allow the

material’s surface to reach its vaporization temperature within milliseconds.

START

Paint the
substrate with
yellow paint

Etch the
substrate with
Raycus LASER

Chemical
Etching Using
Ferric Chloride

Use iso-propyl
alcohol to
remove the paint
stains

Grind the
unwanted
portions using
grinding mill

Connect the
SMA connector
and make the
testing

END

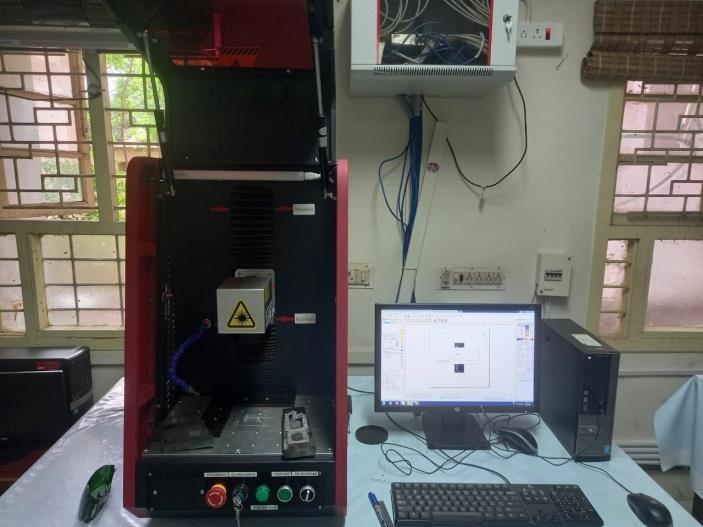
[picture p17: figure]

Figure 45. RAYCUS LASER | Figure 46. IPG LASER

Using the EZCAD software, the image is imported. X and Y coordinates of the design are given as inputs from which many passes are run to etch the design.

### 4.1.2 CHEMICAL ETCHING:

The chemical etching process works by printing a component design on to photo resist

which is laminated onto metal. The areas of photo resist which have not been printed are

removed, exposing the metal, which is subsequently etched away. Chemical etching, also

known as chemical milling or photo etching, is a subtractive sheet metal machining

process which uses chemical etchants to create complex and highly accurate precision

components from almost any metal. Photo-etched components are burr and stress-free

with no mechanical force or heat used, leaving material properties unaltered. Ferric

chloride is one of the most widely used etchants in the field of chemical etching. It is

commonly used to etch steel and stainless steel parts, but it is also capable of etching

copper. One of the reasons it is so popular is because of its versatility.

FeCl3 + Cu → CuCl2+ FeCl

Here the Copper of the substrate reacts with the Ferric Chloride and dissolve in the

solution as CuCl2.In a solution the Ferric chloride and distilled water are mixed in 1:1

ratio to get the perfect etching of the copper.

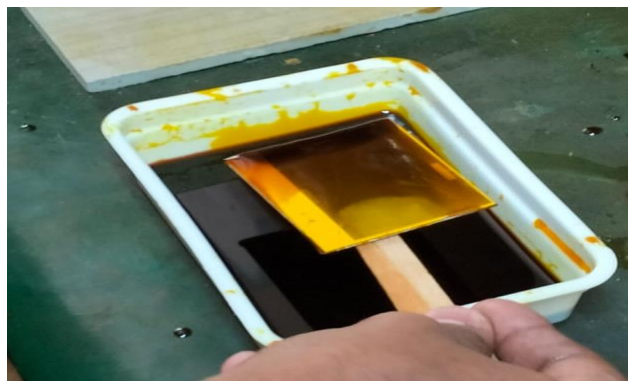
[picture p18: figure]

Figure 47. After reaction with FeCl3

### 4.2 FINAL PREPARATIONS:

After the chemical etching of the laser fabricated material the paint stains in the

material is removed using the Isopropyl alcohol. Isopropyl alcohol (rubbing alcohol)

liquefies the oldest paint. Wet paint thoroughly and cover with plastic to prevent

evaporation. Paint will wash off with water after a short time.

### 4.2.1 PHOTO POLYMERIZATION:

A negative acting photo polymerizable film resist in which a photopolymerizable

layer is sandwiched between a temporary support film and a temporary cover film. This

film has gained widespread usage in the manufacture of printed circuits in which the cover

film is removed, the photopolymerizable layer is laminated by heat and pressure to the

surface, e.g., copper, of a substrate to be permanently modified, the layer is image wise

exposed to actinic radiation, the film support is removed, the unexposed areas of the layer

are removed by solvent washout (development), and the resultant bared area of the copper

surface is permanently modified, such as by etching or deposition of metal.

### 4.2.2 TINNING:

Tinned copper is primarily used for protection against oxidation and corrosion. In

climates where copper has long-term exposure to water, the oxygen will combine with the metal and form copper oxide, weakening the bonds of the metal. It is worse if the wire is

in contact with salt water.

Figure 48. During tinning process

### 4.2.3 GRINDING:

Finally the fabricated antenna is grinded using the grinding machine .Grinding

machine grinds the unwanted area in the antenna. Grinding is used to avoid unnecessary

losses in the substrate while cutting the antenna.

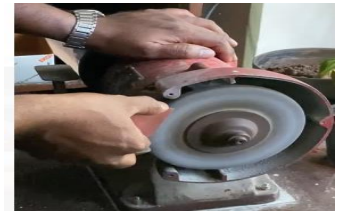
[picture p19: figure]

Figure 49. During Grinding process

### 4.3 LASER DEPANELING:

LASER Depaneling is one of the most modern and promising processes for

separation PCBs from the overall panel. During the depaneling process, the previously

manufactured and assembled printed circuit boards (PCBs) are cut out of the panel using

a suitable separation process/tool. In the case of laser depaneling, the singulation process

is performed by a focused laser beam that ablates the material layer by layer. LPKF

machine (Leiterplatten Kopierfrasen – Circuit Board Copy Milling) is used for this purpose. The LPKF lasers are suitable for cutting all industry-standard panel sizes with

dimensions of up to 533 x 610 mm (2'' x 2''). The 20-μm high-quality UV laser kerf width

allows for cutting of even the most delicate contours at high speeds. The following steps

give a detailed explanation about the step-by-step procedure involved in the fabrication

process.

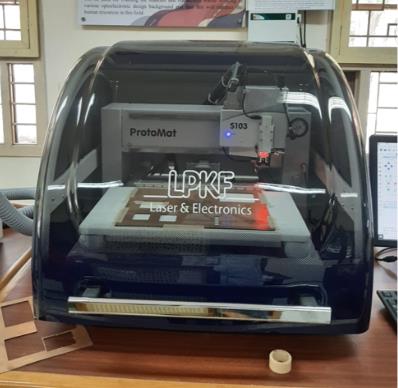
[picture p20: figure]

Figure 50. LPKF Machine

### 4.3.1 STEP 1: EXPORTING THE GERBER FILES:

First step is to export the Gerber files of each layer of the antenna to be fabricated.

- Open CST simulation
- Use pick faces and select the layer
- Align coordinates with WCS.
- Click modelling and select Export GERBER.
- Choose GERBER single layer.

### 4.3.2 STEP 2: IMPORTING THE GERBER FILES:

Gerber files are imported into the CICUITPRO software. Appropriate calibrations are made to have proper etching of the patch.

### 4.3.3 STEP 3: INSERTION OF APPROPRIATE DRILL BEATS:

After importing the Gerber file of the array, drill beats should be chosen such that

accurate etching of the layer is made and holes of proper diameter are made as per the

simulation design.

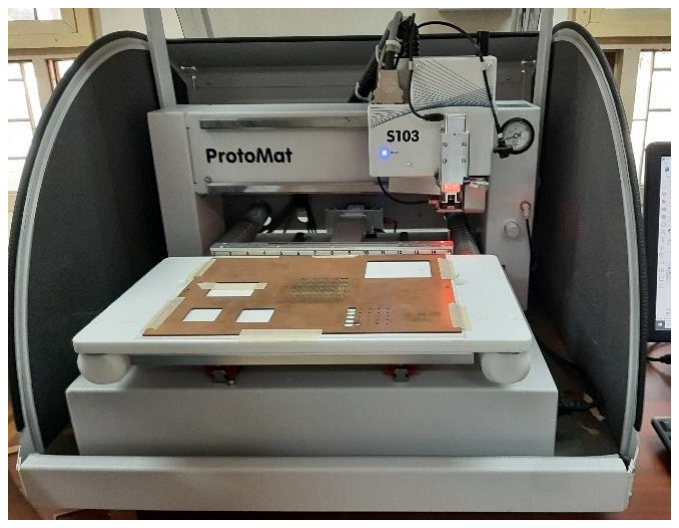
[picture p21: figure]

### 4.3.4 STEP 4: ETCHING OF THE SUBSTRATE:

After STEP 3, many passes have to be made to have perfect etching of the substrate

without any unwanted copper layers. If proper etching is not achieved even after many

iterations, then chemical etching has to be done.

Figure 51. Gerber of the array

Figure 52. Insertion of drills beats

### 4.3.5 STEP 5: SOLDERING OF PORTS:

After the antenna has been etched perfectly, holes are drilled using 1mm drill beat.

Two ports have been inserted and soldered SMA connector with ground plane.

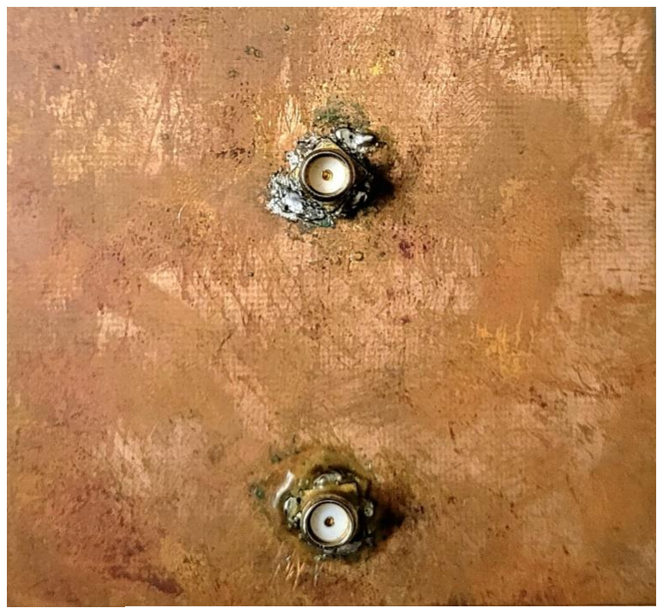
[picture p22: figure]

### 4.4 NETWORK ANALYSER:

A network analyzer is an instrument that measures the network parameters of

electrical networks. Today, network analyzers commonly measure S parameters because

reflection and transmission of electrical networks are easy to measure at high frequencies,

Figure 54. Soldered ports

Figure 53. Etched Substrate but there are other network parameter sets such as y-parameters, z-parameters, and h-

parameters. Network analyzers are often used to characterize two-port networks such as

amplifiers and filters, but they can be used on networks with an arbitrary number of ports.

A VNA (Vector Network analyzer) is a form of RF network analyzer widely used for RF

design applications. A VNA may also be called a gain–phase meter or an automatic

network analyzer.

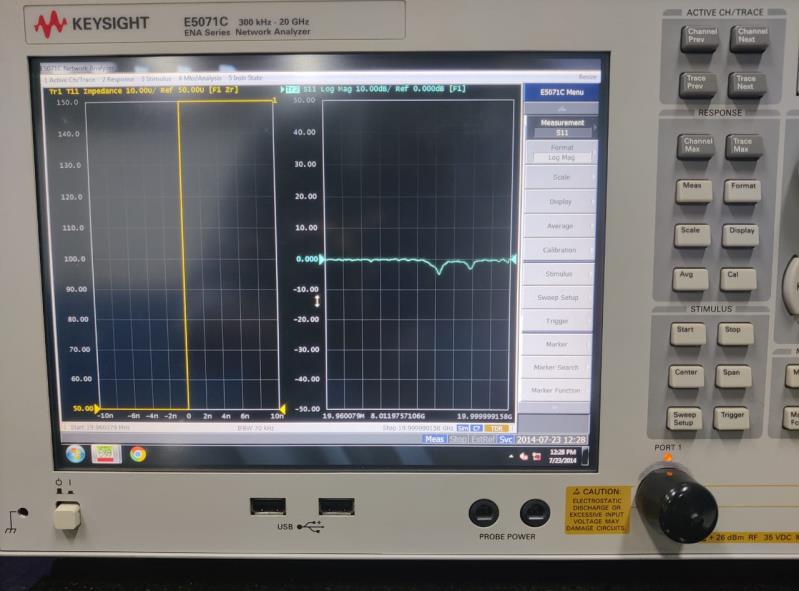
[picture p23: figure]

Figure 55. Vector Network Analyzer

### 4.5 CALIBRATION KIT:

Calibration kit is used to remove the noise which were present in the previous

simulation. It contains three port namely OPEN, SHORT, LOAD .These three ports were

connected to the measuring tube and the noises where removed. CALKIT 85220A is used

for testing.

Figure 56. Calkit 85220A

### 4.6 SMA CONNECTOR:

SMA (SubMiniature version A) connectors are semi-precision coaxial (https://en.wikipedia.org/wiki/Coaxial) RF

connectors (https://en.wikipedia.org/wiki/RF_connector) developed in the 1960s as a minimal connector interface (https://en.wikipedia.org/wiki/Electrical_connector) for coaxial cable (https://en.wikipedia.org/wiki/Coaxial_cable) with

a screw-type coupling mechanism. The connector has a 50 Ω impedance. (https://en.wikipedia.org/wiki/Electrical_impedance) SMA was

originally designed for use from DC (https://en.wikipedia.org/wiki/Direct_current) (0 Hz) to 12 GHz, (https://en.wikipedia.org/wiki/GHz) however this has been extended

over time and variants are available to 18 GHz and 26.5 GHz. There are also mechanically

compatible connectors such as the K-connector which operate up to 40 GHz. The SMA

connector is most commonly used in microwave systems, hand-held radio and mobile

telephone antennas and, more recently, with WiFi antenna systems and USB software-

defined radio (https://en.wikipedia.org/wiki/Software-defined_radio) dongles. It is also commonly used in radio astronomy, (https://en.wikipedia.org/wiki/Radio_astronomy) particularly at higher

frequencies (5 GHz+).

Figure 57. SMA Connector

### CHAPTER 5 FABRICATION RESULTS

### 5.1 RESULTS:

### 5.1.1 RETURN LOSS OF DSRC BAND:

The fabricated antenna using FR4 substrate is tested and analysis were made

using Vector network Analyzer. Following Figure shows the S11 of the fabricated

antenna. The Fabricated antenna has good return loss of -20 decibel.

### 5.1.2 VSWR AT DSRC BAND:

VSWR (Voltage Standing Wave Ratio) is a measure of how

efficiently radio-frequency power is transmitted from a power source, through a

transmission line, into a load. In an ideal system, 100% of the energy is transmitted. This

requires an exact match between the source impedance, the characteristic impedance of

Figure 58. Measured S11 of DSRC band the transmission line and all its connectors, and the load's impedance. The signal's AC

voltage will be the same from end to end since it runs through without interference.

The following plot shows the VSWR at DSRC band. The Ideal value of VSWR should

lie in the range of 1 to 2. The fabricated antenna has good VSWR of 1.02 at DSRC band.

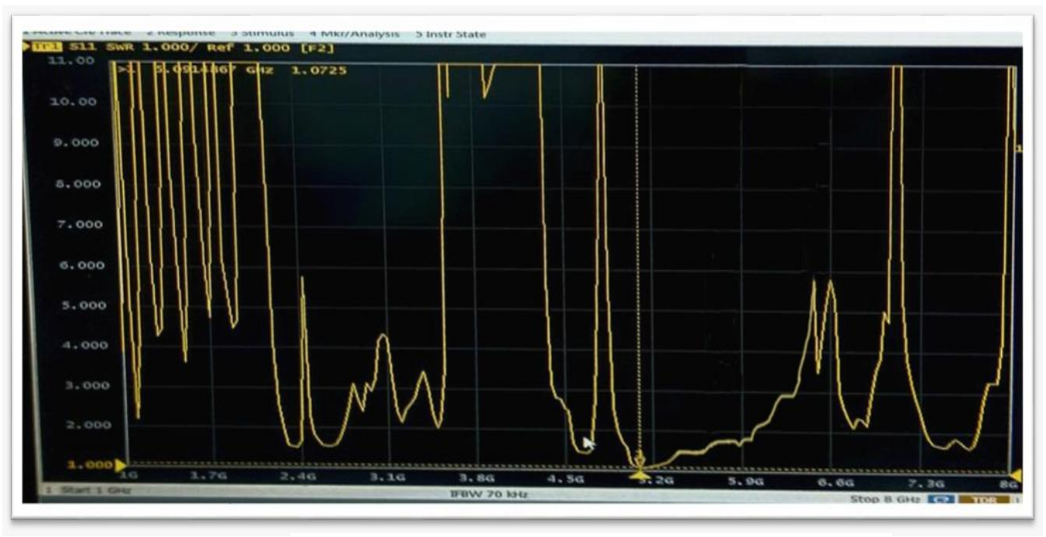
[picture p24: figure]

Figure 59. Measured VSWR at DSRC band

CHAPTER 6

CONCLUSION

In this Project, a Low Profile Dual band shared antenna array has been simulated

and fabricated for Vehicle to Vehicle communication (DSRC band) and 5G mm-wave

band for which the proper isolation between the two ports for DSRC band and 5G mm-

wave band has been achieved by providing differential feed to the patch array operating

at 5.9 GHz and co-printing a series fed array operating at 5G band on the same substrate

in the space within the 5.9 GHz array. Through several iterations and parametric analysis,

the effects of introducing cross slots, truncated corners, varying length and width of patch

and varying thickness of the substrate were studied and as a result, the dimensions have

been reduced from 100 x 75 mm²

to 75 x 75 mm²
for both the antenna arrays made up of

Rogers and FR4 substrates and truncated corners have been introduced in FR4 based

design and cross slots cum truncated corners of appropriate dimensions have been

introduced in the Rogers based design to get better results in terms of radiation pattern,

efficiency, gain and polarization. The antenna designed using Rogers substrate supports

DSRC band at 5.9 GHz with a gain of 10.63 dB and efficiency of 85.41% and 5G mm-

wave band at 26 GHz with a gain of 9.78 dB and efficiency of 95.6%. The antenna

designed using FR4 substrate supports DSRC band at 5.9 GHz with a gain of 6.87 dB and

efficiency of 64.82% and 5G mm-wave band at 28 GHz with a gain of 7.2 dB and

efficiency of 63.21%. From experimental results, the S11 parameters and VSWR plots are

reported and it is concluded that the suggested design can be used for mentioned

applications.

REFERENCES

1. Sandhiya Reddy Govindarajulu , Rimon Hokayem , M D Nurul Anwar Tarek , Marisol

Roman Guerra Elias A. Alwan (October 2021) “Low Profile Dual-Band Shared

Aperture Array for Vehicle-to-Vehicle Communication”.

2. Deven G. Patanvariya, Kalyan S. Kola, Anirban Chatterjee (April 2019) “Left-Handed

Circularly Polarized Two-Element Antenna Array for Vehicular Communication”.

3. Adamantia Chletsou, John F Locke, John Papapolymerou (November 2021) “Vehicle

Platform Effects on Performance of Flexible, Lightweight and Dual-Band Antenna for

Vehicular Communications”.

4. Edith Condo Neira , Jan Carlsson , Kristian Karlsson , Erik G Strom (October 2006)

“Combined LTE and IEEE 802.11p Antenna for Vehicular Applications”.

5. Huapeng Zhao, Xinhui Zhang, Zhizhang Chen, Ying-Chang Liang (May 2021) “A
Hybrid-Equivalent | Surface-Edge | Current | Model | for | Simulation | of V2X

Communication Antennas With Arbitrarily Shaped Contour”.

6. Yuanxi Cao, Sen Yan, Jianxing Li, Juan Chen (July 2022) “A Pillbox Based Dual

Circularly-Polarized Millimeter-Wave Multi-Beam Antenna for Future Vehicular

Radar Applications”.

7. Ani Taggu, Bikram Patir, Utpal Bhattacharjee (March 2017) “A dual band omni-

directional antenna for WAVE and Wi-Fi”.

8. Shobit Agarwal, Ashwani Sharma (November 2020) “A Miniaturized Wideband

Antenna for Vehicular Communication, WiMAX, and WLAN Applications”.
